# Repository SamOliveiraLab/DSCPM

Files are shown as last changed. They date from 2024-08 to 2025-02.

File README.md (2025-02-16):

# The Dual Syringe Continuous Pumping Mechanism (DSCPM)

## Repository for the Article: *A Continuous, Low Flow, and Multiplexing Pumping System for Microfluidics Applications*

This repository contains all software, hardware schematics, and supplementary materials associated with the publication:

[Preprint on bioRxiv](https://www.biorxiv.org/content/10.1101/2024.08.16.608339v1)

### **Contents of This Repository**
- **Arduino Code:**
  - DSCPM 2-3/1-2
  - DSCPM 2-2
  - Fluidic Multiplexers
- **Python Scripts:**
  - Edge-detection scripts for generating volume-infused vs. time and flow rate vs. time plots from pre-cropped horizontal (left-to-right) videos of dyed fluid infusing into micro-bore tubing.  
  - *Note:* Generative AI was utilized in the development of these scripts. The authors have rigorously validated the generated quantitative data against raw video data and assume full responsibility for its accuracy.
- **3D Printable Components:**
  - STL files for DSCPM parts.

---

## **Repository Structure**

### **Main Directory**
- **Appendix A**  
  - Hardware and microfluidic chamber design files.
  - `.stl` files for 3D-printed components (e.g., syringe plunger, valve holder).
  - `.gds` files for microfluidic monolayer geometries (Layer 1 & Layer 2).

- **Appendix B**  
  - Integrated Arduino `.ino` files for DSCPM pumps and fluidic multiplexers.
  - Graphical User Interface (GUI) that interfaces with the Arduino via serial communication to control the pump system.

- **Appendix C**  
  - Data files and analysis scripts.
  - Jupyter notebooks (`.ipynb`) and MATLAB scripts (`.m`) are used to process experimental data presented in the paper.

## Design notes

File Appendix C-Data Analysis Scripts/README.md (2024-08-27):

# Flow Rate versus Time Measurments

An image processing technique was used to measure flow rate versus time in the study: *A Continuous, Low Flow, Multiplexing Pumping System for Microfludidics Applications*

First, raw data was collected by infusing blue dyed water through micro bore tubing and filming horizontal videos of the infusion. The videos were then cropped to only include the tubing. The cropping doesn't need to be perfect, since only vertical edge detection is performed, but including as few background pixels as possible will increase the acuracy of the algorithm.

The length of tubing in the frame was noted for later use in data processing.

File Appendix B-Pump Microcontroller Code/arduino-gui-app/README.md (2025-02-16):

# Arduino GUI Application

This project is a GUI application designed to enable serial communication with an Arduino. It features controls for managing a variable called flow rate and direction, allowing for easy interaction and monitoring.

## Project Structure

```
arduino-gui-app
├── src
│   ├── main.py              # Entry point for the application
│   ├── gui
│   │   └── app.py           # GUI implementation
│   ├── serial
│   │   └── communication.py  # Serial communication management
│   └── utils
│       └── simulator.py      # Simulated functions for testing
├── requirements.txt          # Project dependencies
└── README.md                 # Project documentation
```

## Setup Instructions

1. Clone the repository:
   ```
   git clone <repository-url>
   cd arduino-gui-app
   ```

2. Install the required dependencies:
   ```
   pip install -r requirements.txt
   ```

## Usage

To run the application, execute the following command:
```
python src/main.py
```

The GUI will open, allowing you to control the flow rate and direction. Use the slider and text box to set the flow rate, and toggle the switch to change the direction.

## Future Development

- Implement the actual serial communication in `communication.py`.
- Enhance the GUI with additional features as needed.
- Consider adding error handling for serial communication.

## Notes

# Arduino GUI Application

This project is a GUI application designed to enable serial communication with an Arduino. It features controls for managing a variable called flow rate and direction, allowing for easy interaction and monitoring.

## Project Structure

```
arduino-gui-app
├── src
│   ├── main.py              # Entry point for the application
│   ├── gui
│   │   └── app.py           # GUI implementation
│   ├── serial
│   │   └── communication.py  # Serial communication management
│   └── utils
│       └── simulator.py      # Simulated functions for testing
├── requirements.txt          # Project dependencies
└── README.md                 # Project documentation
```

## Setup Instructions

1. Clone the repository:
   ```bash
   git clone <repository-url>
   cd arduino-gui-app
   ```

2. Install the required dependencies:
   ```bash
   pip install -r requirements.txt
   ```

## Usage

To run the application, execute the following command:
```bash
python src/main.py
```

The GUI will open, allowing you to control the flow rate and direction. Use the slider and text box to set the flow rate, and toggle the switch to change the direction.

## Future Development

- Implement the actual serial communication in `communication.py`.
- Enhance the GUI with additional features as needed.
- Consider adding error handling for serial communication.

## Notes

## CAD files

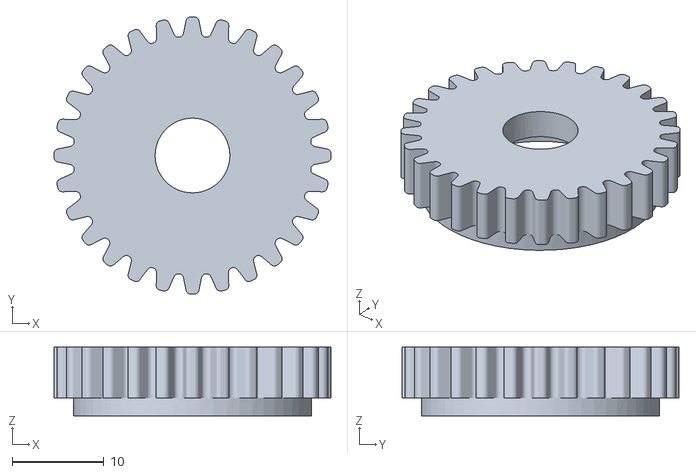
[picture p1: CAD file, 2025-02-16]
Appendix A-STL and GDS Files/Pinion_Gear_with_Hole.stl
30.2 x 30.2 x 7.51

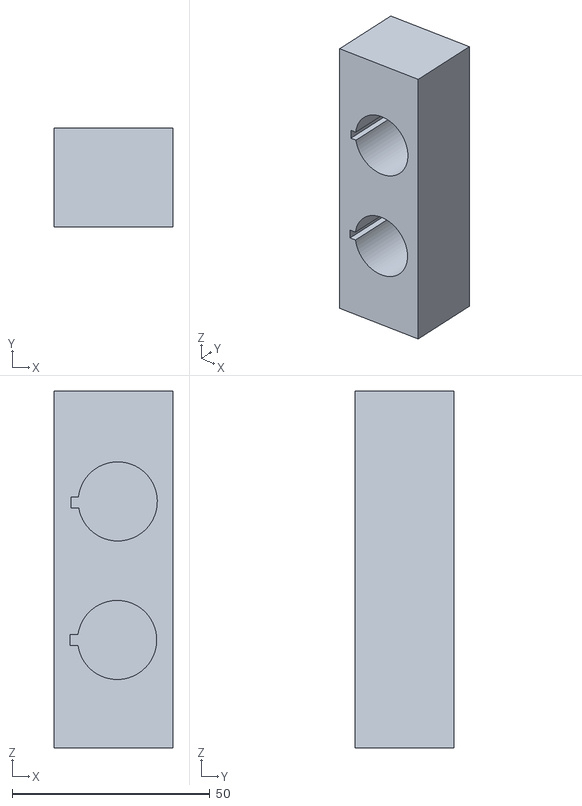
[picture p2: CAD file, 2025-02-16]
Appendix A-STL and GDS Files/DSCPM_Housing_Pinch_valve_holder.stl
30.0 x 25.0 x 90.2

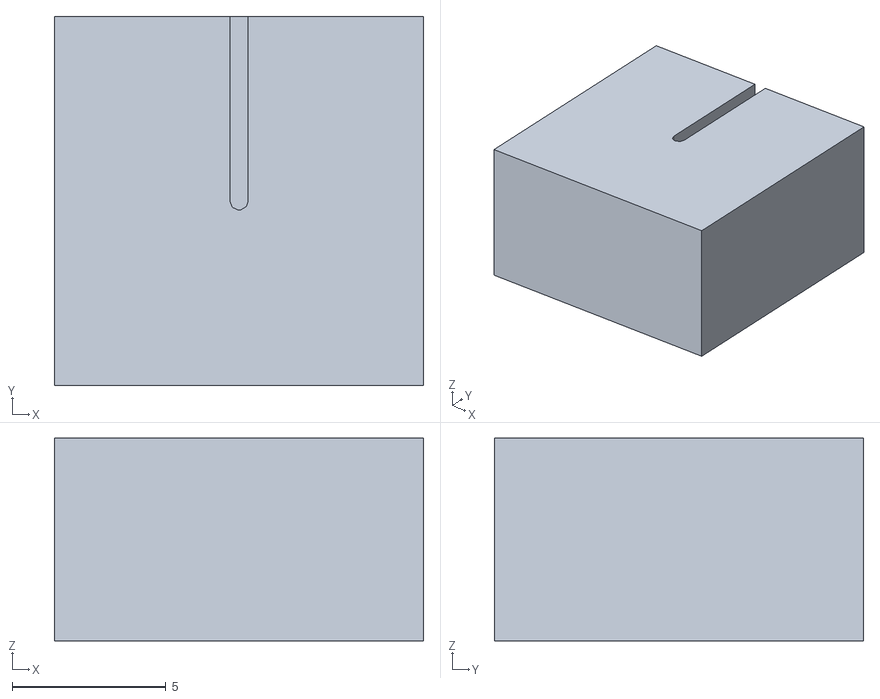
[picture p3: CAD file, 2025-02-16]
Appendix A-STL and GDS Files/DSCPM_Housing_10ul_syringe_plunger_End_Accessory.stl
12.0 x 12.0 x 6.60

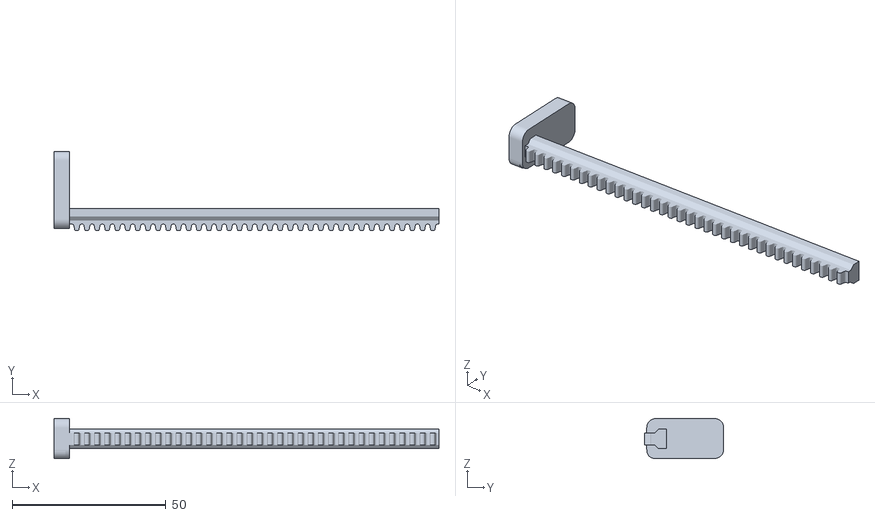
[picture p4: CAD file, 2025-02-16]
Appendix A-STL and GDS Files/Pusher_125mm_Long.stl
125.0 x 25.8 x 13.0

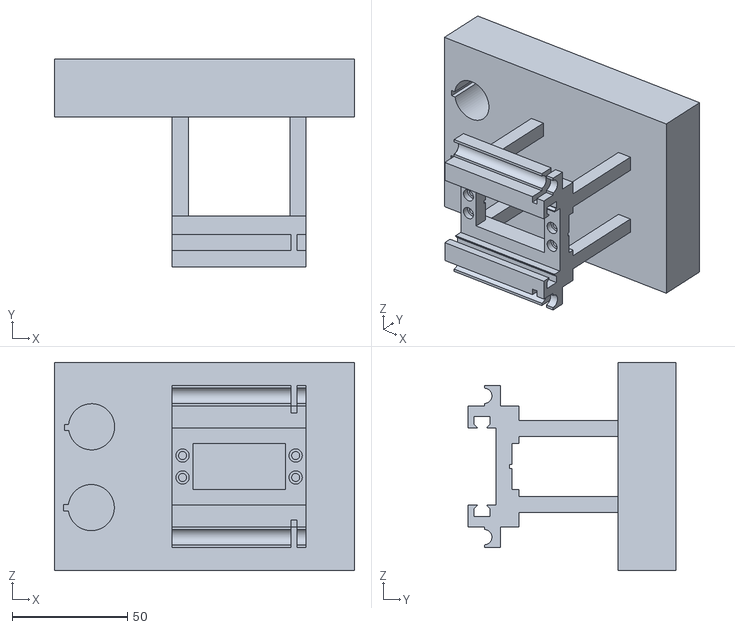
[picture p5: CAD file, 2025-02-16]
Appendix A-STL and GDS Files/DSCPM_Housing_DSCPM_Base.stl
130.0 x 90.0 x 90.2

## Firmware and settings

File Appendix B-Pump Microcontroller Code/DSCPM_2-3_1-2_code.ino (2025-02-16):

//Code for the Dual Syringe Continuous Pumping Mechanism (2-3/1-2)
//By BU 2023 iGEM, K. Walp

#include <Servo.h>
#include <math.h>
#include <EEPROM.h>

Servo myservo;
Servo servo;

String incomingByte = "1";

// --------------------------------------------------------- EEPROM Initializers ------------------------------

// Is it your first time uploading this code to an Arduino? UNCOMMENT the next 3 lines :)
int infuse = 1;
int pos = 5; 
int fwd = 0;

// Once you've run the code once and stored your values properly by pausing before turning off, comment these out!

// -------------------------------------------------------- End EEPROM Initializers ---------------------------

// DEFAULT STATE (ON or OFF)
int on = 1; 

// ------------------------------------------------------ EEPROM Statements (Second run and after) ------------

// Comment these out the first time you run your code, or it will not work properly!
//int infuse = EEPROM.read(2);
//int pos = EEPROM.read(0); 
//int fwd = EEPROM.read(1);
////int pos = 15;
// Once you've run your code once and properly stored your values, uncomment these!

// --------------------------------------------------------- End EEPROM Statements ----------------------------


int s1valve = 5; //pin assignments
int s2valve = 6; //pin assignments
int s3valve = 10; //pin assignments NORMALLY ON, IT MUST BE NORMALLY ON!!!!!!!!!!

//int valvestate = 0; // 0 if s1valve is HIGH, 1 if s2valve is HIGH
int valvestate = EEPROM.read(3);

int ODremainder = 100; // overdrive time remainder, reset here and in incrementposition

float amountpumped = 0;

int holdvoltage = 80; //2.35 V, test with your valves.
int maxangle = 70;
int minangle = 5;




// PARAMETERS SET BELOW. READ COMMENTS BEFORE CHANGING ANYTHING.
//------------------------------------------------------------------------
// Inner Diameter of syringes IN MILLIMETERS!
// 0.485mm ID for Hamilton 10µL syringes, but subject to change by user
//
float innerdiameter = 0.485; 
//
//------------------------------------------------------------------------
// Milimeters of Linear Motion per Degree of Rotation from Servo
// 0.256mm for iGEM Linear Servo Actuators V2 (design as of June 15, 2023)
//
float mmperdegree = 0.256;
//
//------------------------------------------------------------------------
// volmultiplier is calculated to take into account that 
// SERVOS DO NOT TURN EXACTLY 180 DEGREES WHEN YOU TELL THEM TO!!!
// Test you servo: write it to 0 degrees, and then to "180" degrees.
// Measure the actual number of degrees that it turns and enter it below:
// Value is 270 for 2023 iGEM GoBilda High Torque Servos
//
float degper180 = 270;
//
float volmultiplier = degper180 / 180.0;
//------------------------------------------------------------------------
// NOTE: One cubic millimeter is one microliter.
//------------------------------------------------------------------------
// For internal use only. Do Not Change.
//
float innerradius = innerdiameter / 2;
float uLperdeg = 3.1415926536 * (innerradius * innerradius) * (mmperdegree * volmultiplier); 
//------------------------------------------------------------------------
// PARAMETERS FINISHED.

//~~~~~~~~~~~~~ SET DEFAULT FLOW RATE BELOW ~~~~~~~~~~~~~~~~~~~
//
float flowrate = 1.5; // µL/min 
//
// DO NOT EXCEED 40 OR THERE WILL BE COMPLICATIONS!!!!!!!!!!!!!!!!!!
//
//~~~~~~~~~~~~~ SET FLOW RATE ABOVE ~~~~~~~~~~~~~~~~~~~~

//----------more params---------------------------------------------------

float minperdeg = uLperdeg / flowrate; // minutes per degree for given flow rate
float millisperdeg = minperdeg * 60000; // milliseconds per degree for given flow rate
int newdelay = int(millisperdeg); // int version of milliseconds per degree to be put in delay

//------------------------------------------------------------------------

void calculatenewdelay(int newflowrate){
  uLperdeg = 3.1415926536 * (innerradius * innerradius) * (mmperdegree * volmultiplier); 
  minperdeg = uLperdeg / flowrate;
  millisperdeg = minperdeg * 60000;
  newdelay = int(millisperdeg);
}

struct posandfwd {
  int pos;
  int fwd;
};

struct posandfwd IncrementPosition(int pos, int fwd, char valvea, char valveb, int infuse, int on){
   if (on == 1){
    if (pos == minangle){
      if (infuse == 0){ 
        valvestate = 1; // b high
      }
      else if (infuse == 1){
        valvestate = 0; // a high
      }
      fwd = 0;
      pos = pos + 1;
      ODremainder = 100;
    }
    else if (pos == maxangle){ // it rips the gears apart if its more than 120 :(
      if (infuse == 0){
        valvestate = 0; // a high
      }
      else if (infuse == 1){
        valvestate = 1; // b high
      }
      fwd = 1;
      pos = pos - 1;
      ODremainder = 100;
    }
    else{ //pos is anything else
      if (fwd == 0){
        pos = pos + 1;
      }
      else if (fwd == 1){
        pos = pos - 1;
      }
    }
  }
  struct posandfwd pos_and_fwd;
  pos_and_fwd.pos = pos;
  pos_and_fwd.fwd = fwd;
  return pos_and_fwd;
}

void overdriveAndDelay(bool remainder, int pos, int valvestate, int newdelay){ // MUST call at each iteration cuz of remainder
  if(remainder){
    //Serial.print("remainder");
    if(ODremainder > newdelay){
      //Serial.print("ODR > ND");
      if(valvestate == 0){
        analogWrite(s1valve, 255);
        analogWrite(s2valve, 0);
      }
      else if(valvestate == 1){
        analogWrite(s1valve, 0);
        analogWrite(s2valve, 255);
      }
      //Serial.println("on1");
      ODremainder = ODremainder - newdelay;
      delay(newdelay);
    }
    else if(ODremainder < newdelay && ODremainder > 0){
      //Serial.print("ODR < ND");
      if(valvestate == 0){
        analogWrite(s1valve, 255);
        analogWrite(s2valve, 0);
        delay(ODremainder);
        analogWrite(s1valve, holdvoltage);
        delay(newdelay - ODremainder);
        ODremainder = 0;
      }
      else if(valvestate == 1){
        analogWrite(s1valve, 0);
        analogWrite(s2valve, 255);
        delay(ODremainder);
        analogWrite(s2valve, holdvoltage);
        delay(newdelay - ODremainder);
        ODremainder = 0;
      }
      //Serial.println("on2");
    }
    else if(ODremainder == 0){
      //Serial.print("ODR = zero");
      delay(newdelay);
    }
  }
  else{ // no remainder
    Serial.print("NO remainder");
    if (pos == minangle || pos == maxangle){
      if (valvestate == 0){ // a high
        analogWrite(s3valve, 255);
        delay(10);
        analogWrite(s1valve, 255);
        analogWrite(s2valve, 0);
        //Serial.println("on1__nana");
        delay(50);
        analogWrite(s3valve, 0);
        delay(100);
        analogWrite(s1valve, holdvoltage);
        //Serial.println("on2__nana");
        delay(newdelay-160);
      }
      else if (valvestate == 1){ // b high
        analogWrite(s3valve, 255);
        delay(10);
        analogWrite(s1valve, 0);
        analogWrite(s2valve, 255);
        //Serial.println("on1__anan");
        delay(50);
        analogWrite(s3valve, 0);
        delay(100);
        analogWrite(s2valve, holdvoltage);
        //Serial.println("on2__anan");
        delay(newdelay-160);
      }
    }
    else{
      /*if (valvestate == 0){ // a high
        analogWrite(s1valve, 70);
        analogWrite(s2valve, 0);
      }
      else if (valvestate == 1){ // b high
        analogWrite(s1valve, 0);
        analogWrite(s2valve, 70);
      }*/
      delay(newdelay);
    }
  }
}

void setup() {
  //solenoid valves setup
  pinMode(s1valve, OUTPUT); //LOW is PUMP, HIGH is REFILL
  pinMode(s2valve, OUTPUT); //LOW is PUMP, HIGH is REFILL

  //servos setup slay
  myservo.attach(9);
  servo.attach(11);
  
  Serial.begin(9600);
}

void loop() {
  // -------------------------------------------TO BE REPLACED WITH I2C RECIEVER STATEMENTS (start)-------------------------------------------
  if (Serial.available() > 0){
    incomingByte = Serial.readString();

    if (incomingByte.toInt() == 0){  //powering system off
      EEPROM.write(0, pos); //------------------------------------------EEPROM------------
      EEPROM.write(1, fwd);
      EEPROM.write(2, infuse);
      EEPROM.write(3, valvestate);
      Serial.print("Position of ");
      Serial.print(pos);
      Serial.println(" degrees saved to EEPROM at index 0");
      on = 0;
    }

    else if (incomingByte.toInt() == 123){ // system on
        on = 1;
        Serial.println("Pumps ON");
    }
    else if (incomingByte.toInt() == 321){ // switch direction OBSOLETE
      if (fwd == 1){
        fwd = 0;
        if (infuse == 0){
          infuse = 1;
        }
        else if (infuse == 1){
          infuse = 0;
        }
      }
      else if (fwd == 0){
        fwd = 1;
        if (infuse == 0){
          infuse = 1;
        }
        else if (infuse == 1){
          infuse = 0;
        }
      }
      Serial.println("Direction Switched");
    }

    else { //chaning flowrate
      flowrate = incomingByte.toInt();
      calculatenewdelay(flowrate);

      Serial.print("Flow Rate Changed to ");
      Serial.print(flowrate);
      Serial.println(" µL/min");
    }
  }

  // -------------------------------------------TO BE REPLACED WITH I2C RECIEVER STATEMENTS (end)-------------------------------------------

  struct posandfwd posandfwd_ = IncrementPosition(pos, fwd, s1valve, s2valve, infuse, on);
  pos = posandfwd_.pos;
  fwd = posandfwd_.fwd;

  if (on == 1){
    if (infuse == 0){
      amountpumped = amountpumped + uLperdeg;
    }
    else if (infuse == 1){
      amountpumped = amountpumped - uLperdeg;
    }
  }

  myservo.write(pos);
  Serial.print(pos);
  Serial.print(", ");
  Serial.print(amountpumped);
  Serial.print(" µL, ");

  if (newdelay >= 100){
    overdriveAndDelay(false, pos, valvestate, newdelay);
  }
  else if (newdelay < 100){
    overdriveAndDelay(true, pos, valvestate, newdelay);
  }
  
  Serial.println(newdelay);

}

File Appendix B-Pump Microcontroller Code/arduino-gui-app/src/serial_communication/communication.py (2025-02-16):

import serial
import random
import time
from datetime import datetime

# Initialize serial communication
# Adjust the COM port and baud rate as per your Arduino setup
# ser = serial.Serial(port='COM3', baudrate=9600, timeout=1)


def communicate(command):
    """
    Communicates with the Arduino: sends a command, waits for a response, and logs data.
    """
    try:
        # Encode the command
        data = encode(command)

        # Send the encoded command one at a time
        for i in data:
            tx(i)
            time.sleep(0.1)  # Delay between sending each character

        # Wait for completion with a timeout
        # remove input cammond when doing hardware integreation
        active_data = rx(command)

        # Decode the received data
        active_value = decode(active_data)

        # Log the communication to a file
        log_data(command, active_value)

    except Exception as e:
        print(f"Error in communication: {e}")


def tx(data):
    """
    Sends encoded data to the Arduino using the serial Tx line.
    """
    if data is not None:
        # ser.write(data.encode())  # Convert to bytes and send over serial
        print(f"Sent: {data}")
    else:
        print("Readonly mode - no data sent.")


def rx(data):  # remove input cammond when doing hardware integreation
    """
    Reads encoded data from the Arduino using the serial Rx line with timeout functionality.
    """
    timeout = 5  # seconds
    start_time = time.time()

    while True:
        if time.time() - start_time > timeout:
            print("Timeout waiting for response from Arduino.")
            return None  # Indicate a timeout occurred

        # Simulate reading from Arduino (replace with actual serial reading in production)
        # response = ser.readline().decode().strip()  # Uncomment this in actual implementation

        if data is None:
            response = 8 * random.randint(-75, 75)  # Simulated response
        else:
            response = data  # Simulated response

        if response:  # Check if a response is received
            # print(f"Received: {response}")
            return response  # Return the received response


def encode(command):
    """
    Encodes a command into the format expected by the Arduino and returns a vector.

    Input:
        command: signed float or None
            - Positive -> [123, absolute value of the command]
            - Negative -> [321, absolute value of the command]
            - Zero -> [stop: -1, 0]
            - None -> [readonly: None, None]  # Read-only mode

    Special Case:
        If the absolute value of the command equals 123 or 321 (reserved codes),
        adjusts the flow rate by +1 or -1, respectively.

    Output:
        A vector [code, value], where `code` is the direction command and `value` is the flow rate.
    """
    if command is None:
        return [None, None]  # Read-only mode

    try:
        # Convert the command to a float
        command = float(command)
        direction = 123 if command > 0 else 321 if command < 0 else -1
        flow_rate = abs(command)

        # Adjust flow rate if it equals a reserved code
        if flow_rate == 123:
            flow_rate += 1
        elif flow_rate == 321:
            flow_rate -= 1

        return [direction, flow_rate]
    except ValueError:
        # Handle invalid input
        return ["Invalid", None]


def decode(data):
    """
    Decodes the data received from the Arduino.
    """
    try:
        # Assuming the Arduino sends only the active_value
        return float(data)  # Convert to float for numerical logging
    except ValueError:
        print("Failed to decode data.")
        return None


def log_data(command, active_value):
    """
    Logs data to a file in the specified format: datetime, set_value (command), active_value.
    """
    if active_value is not None:
        with open("pump_log.csv", "a") as log_file:
            log_file.write(
                f"{datetime.now()}, {command}, {active_value}\n")
        print(
            f"Logged: {datetime.now()}, {command}, {active_value}")


# Example usage
""" if __name__ == "__main__":
    print("Starting Arduino communication. Type 'exit' to quit.")
    try:
        while True:
            user_command = input(
                "Enter a command (): ").strip()
            if user_command.lower() == "exit":
                print("Exiting program.")
                break
            communicate(user_command)
    except KeyboardInterrupt:
        print("\nProgram interrupted. Exiting.")
 """
